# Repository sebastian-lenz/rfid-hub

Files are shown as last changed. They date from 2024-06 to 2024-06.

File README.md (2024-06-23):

# RFID Hub

The RFID Hub is a C++ project designed to utilize the Raspberry Pi Pico 
microcontroller to interface with up to four RFID readers. Each RFID reader 
acts as a unique keyboard input, allowing  users to simulate keystrokes by
presenting RFID tags to the readers. 

## Compiling

This project uses Platform.IO, please visit https://platformio.org/ to find
out more. After installing Platform.IO this project can be build using the 
following command:

```
$ pio run
```

If a Raspberry Pico is connected the project can be build and uploaded to
the board using the following command:

```
$ pio run -t upload -e pico
```

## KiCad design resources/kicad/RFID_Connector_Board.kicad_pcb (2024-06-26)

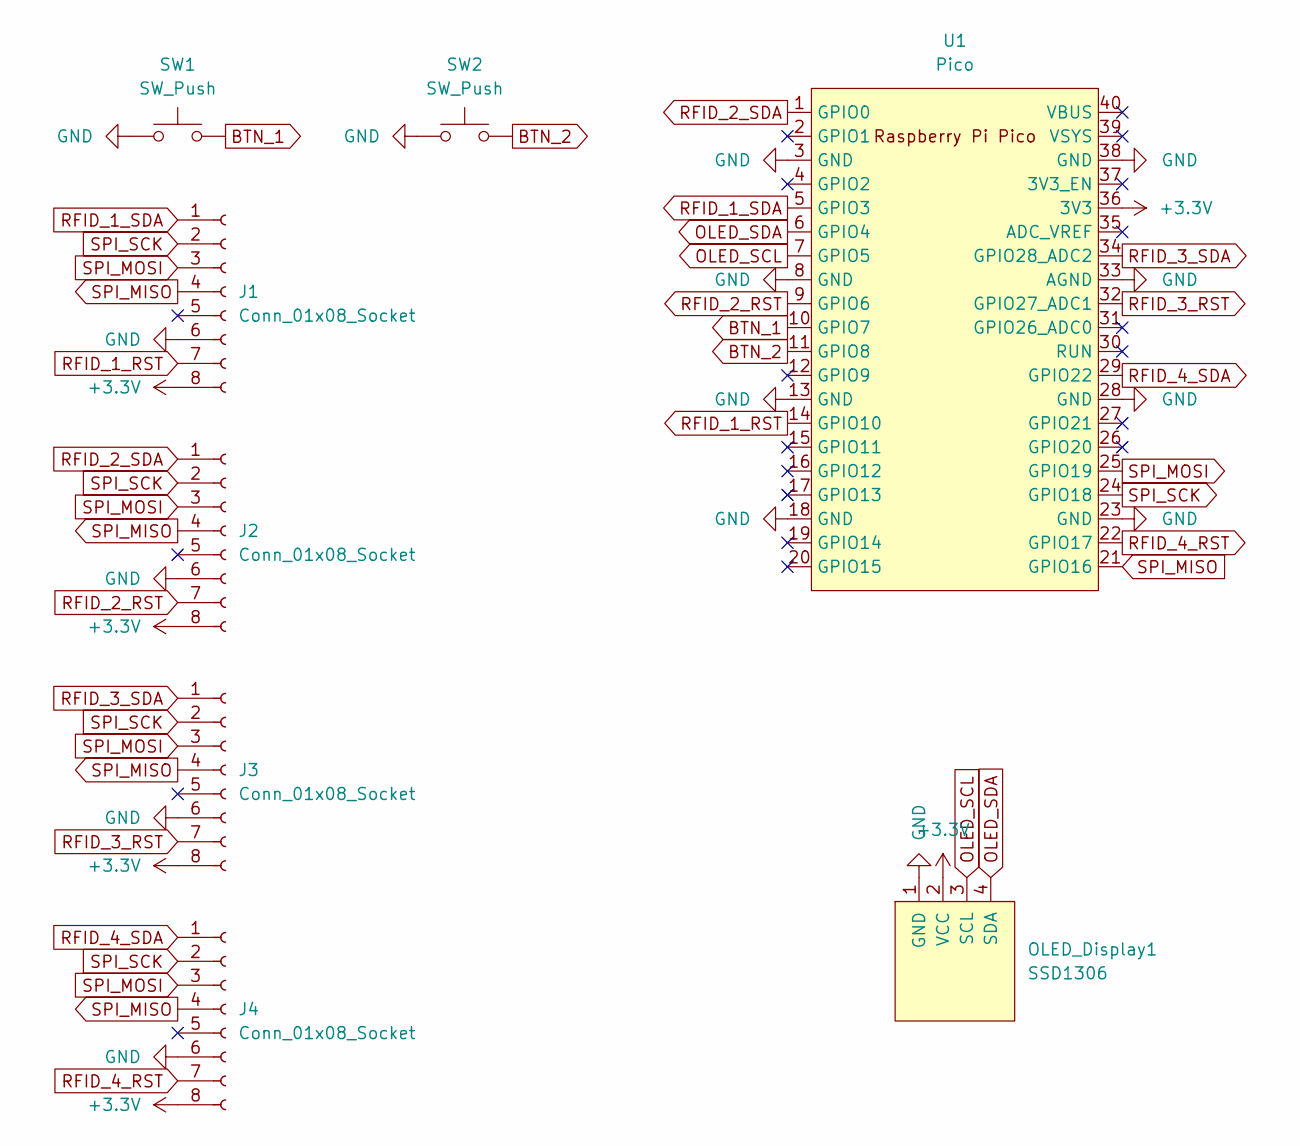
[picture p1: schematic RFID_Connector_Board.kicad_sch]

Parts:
J1, J2, J3, J4: Conn_01x08_Socket; JST_EH_S8B-EH_1x08_P2.50mm_Horizontal
OLED_Display1: SSD1306; 128x64OLED_1.3
SW1, SW2: SW_Push; SW_PUSH_6mm_H7.3mm
U1: Pico; RPi_Pico_SMD_TH_Simple

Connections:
+3.3V: J1.8, J2.8, J3.8, J4.8, OLED_Display1.2 (VCC), U1.36 (3V3)
BTN_1: SW1.2, U1.10 (GPIO7)
BTN_2: SW2.2, U1.11 (GPIO8)
GND: J1.6, J2.6, J3.6, J4.6, OLED_Display1.1 (GND), SW1.1, SW2.1, U1.3 (GND), U1.8 (GND), U1.13 (GND), U1.18 (GND), U1.23 (GND), U1.28 (GND), U1.33 (AGND), U1.38 (GND)
OLED_SCL: OLED_Display1.3 (SCL), U1.7 (GPIO5)
OLED_SDA: OLED_Display1.4 (SDA), U1.6 (GPIO4)
RFID_1_RST: J1.7, U1.14 (GPIO10)
RFID_1_SDA: J1.1, U1.5 (GPIO3)
RFID_2_RST: J2.7, U1.9 (GPIO6)
RFID_2_SDA: J2.1, U1.1 (GPIO0)
RFID_3_RST: J3.7, U1.32 (GPIO27_ADC1)
RFID_3_SDA: J3.1, U1.34 (GPIO28_ADC2)
RFID_4_RST: J4.7, U1.22 (GPIO17)
RFID_4_SDA: J4.1, U1.29 (GPIO22)
SPI_MISO: J1.4, J2.4, J3.4, J4.4, U1.21 (GPIO16)
SPI_MOSI: J1.3, J2.3, J3.3, J4.3, U1.25 (GPIO19)
SPI_SCK: J1.2, J2.2, J3.2, J4.2, U1.24 (GPIO18)

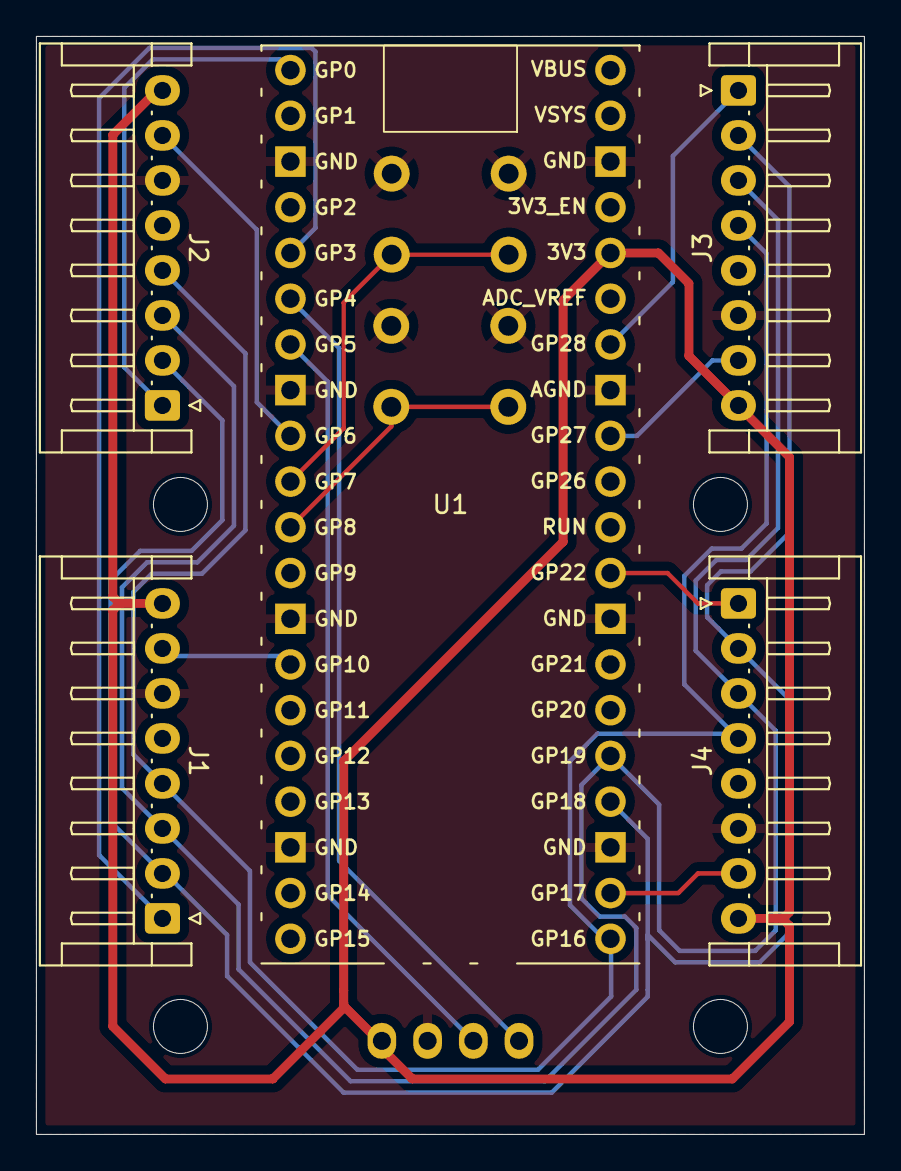
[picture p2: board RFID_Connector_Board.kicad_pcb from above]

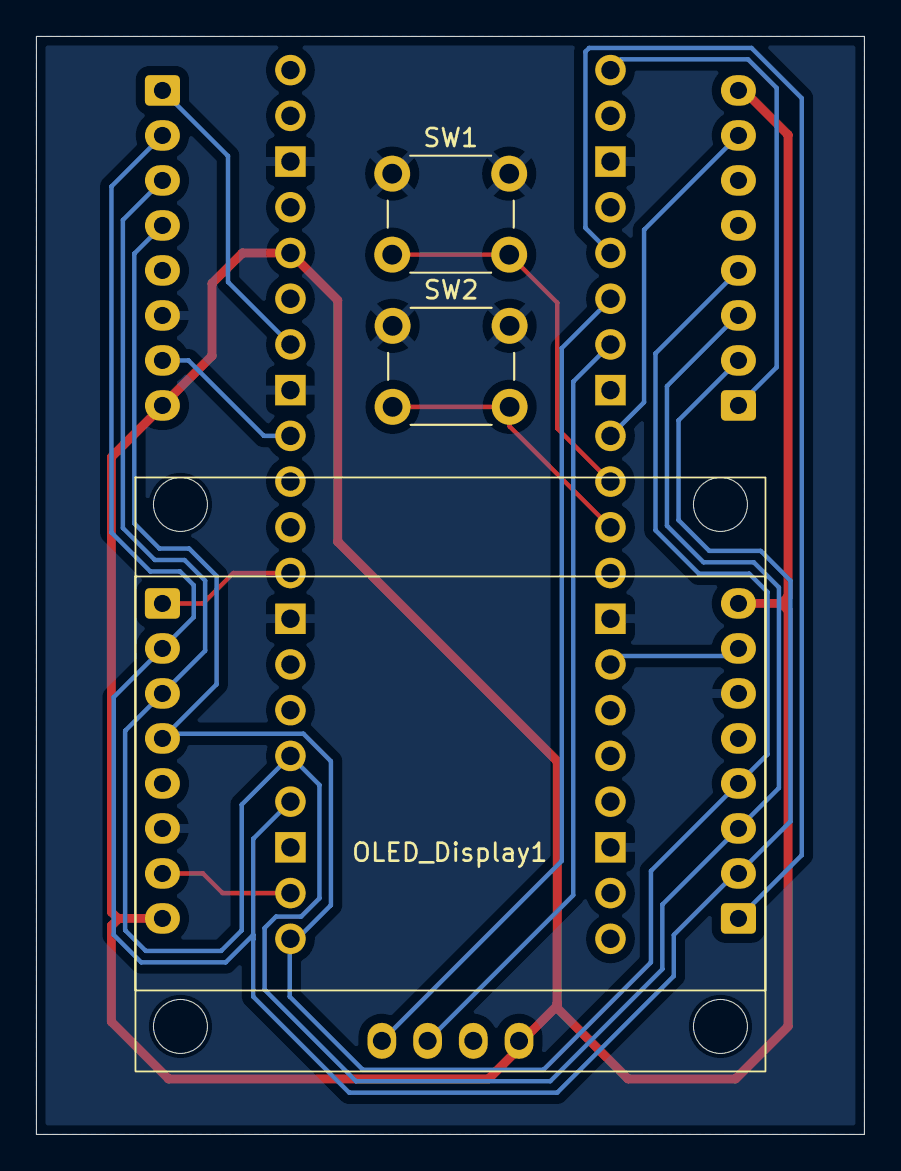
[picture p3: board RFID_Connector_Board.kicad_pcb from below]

Board: 2 copper layers, 46.0 x 61.0 mm, 8 parts (3 on the bottom side), 17 nets.

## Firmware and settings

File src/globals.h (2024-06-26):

#ifndef RFID_HUB_GLOBALS_H
#define RFID_HUB_GLOBALS_H

#include <U8g2lib.h>
#include "base/EventDispatcher.h"
#include "hid/Settings.h"
#include "hid/Sensor.h"
#include "ui/Button.h"

#define DEBUG false

#define NUM_SENSORS 4
#define SENSOR_0  3, 10
#define SENSOR_1  0,  6
#define SENSOR_2 28, 27
#define SENSOR_3 22, 17

#define NUM_BUTTONS 2
#define BUTTON_0 8
#define BUTTON_1 7

#define SCREEN_WIDTH 128
#define SCREEN_HEIGHT 64

extern U8G2_SH1106_128X64_NONAME_F_HW_I2C u8g2;
extern EventDispatcher dispatcher;
extern Sensor sensors[NUM_SENSORS];
extern Button buttons[NUM_BUTTONS];
extern Settings settings;

void log(const String &message);

#endif //RFID_HUB_GLOBALS_H

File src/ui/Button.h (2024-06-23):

#ifndef RFID_HUB_BUTTON_H
#define RFID_HUB_BUTTON_H

#include <Arduino.h>

enum class ButtonSignal {
  NONE,
  PRESS,
  RELEASE,
  REPEAT,
};

class Button {
private:
  const uint _buttonPin;
  bool       _isPressed = false;
  long       _pressedFrames = 0;

public:
  explicit Button(uint buttonPin)
    : _buttonPin(buttonPin)
  { }

  void begin() const {
    gpio_init(_buttonPin);
    gpio_set_dir(_buttonPin, GPIO_IN);
    gpio_pull_up(_buttonPin);
  }

  ButtonSignal update() {
    bool isPressed = !gpio_get(_buttonPin);
    bool didChange = _isPressed != isPressed;
    _isPressed = isPressed;

    if (didChange) {
      _pressedFrames = -6;
      return isPressed
        ? ButtonSignal::PRESS
        : ButtonSignal::RELEASE;
    }

    if (isPressed) {
      _pressedFrames += 1;
      return _pressedFrames > 0 && _pressedFrames % 4 == 0
        ? ButtonSignal::REPEAT
        : ButtonSignal::NONE;
    }

    return ButtonSignal::NONE;
  }

  [[nodiscard]]
  bool isPressed() const {
    return _isPressed;
  }
};

#endif //RFID_HUB_BUTTON_H

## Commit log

2024-06-26 Update button pins
2024-06-26 Add KiCad project
    [RFID_Connector_Board.kicad_pcb, RFID_Connector_Board.kicad_sch]
